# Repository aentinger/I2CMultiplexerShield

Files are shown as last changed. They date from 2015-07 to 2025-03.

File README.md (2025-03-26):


💾 I2C Multiplexer Shield
=========================



# 📸 Image

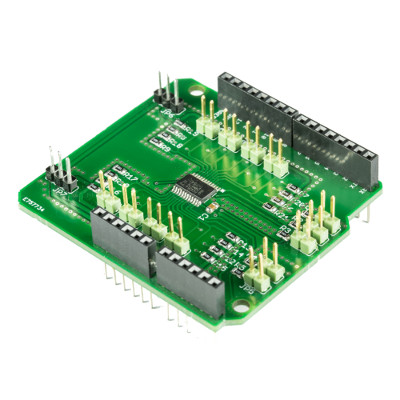
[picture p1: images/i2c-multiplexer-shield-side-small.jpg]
LXRobotics P19 I2C Multiplexer Shield


# 📂 Description

Originally many I2C slave devices as temperature sensors, distance sensors, RAM/ROM, digital I/O expanders had only a single I2C address. As a consequence, only one such I2C slave could be operated on one I2C. If one wanted to operate multiple I2C slaves with identical address, multiple I2C buses with its own I2C master were necessary. To overcome this limitation, modern I2C slaves have a base address, which can be varied by setting of '0' and '1' on special address pins. Thereby, typically between 4 and 8 different addresses are required per I2C slave. But if onw would want to use more than the addresses offered by the I2C slave device, so again several I2C buses with its own I2C master are necessary.

The LXRobotics I2C Multiplexer Shield solves this problem by allowing the user to switch back and forth between 8 different I2C bus systems. The I2C Multiplexer Shield acts also as a level converter, so that 3,3 V I2C sensors can easily interact with the Arduino. For the quick start, a finished Arduino Library with sample programs is available

**Features**

* Control nearly any number of (similar) sensors over a single I2C bus
* Multiplexing of 8 different I2C buses on 1 I2C bus
* I2C-Pullups via Jumper shiftable
* Selection of the I2C bus voltage between 5 V and 3,3 V via jumper possible (optionally, can be also fed any arbitrary I2C bus voltage)
* Up to 8 different I2C addresses of the I2C Multiplexer Shields configurable via jumper
* Arduino Library available for control with example programms

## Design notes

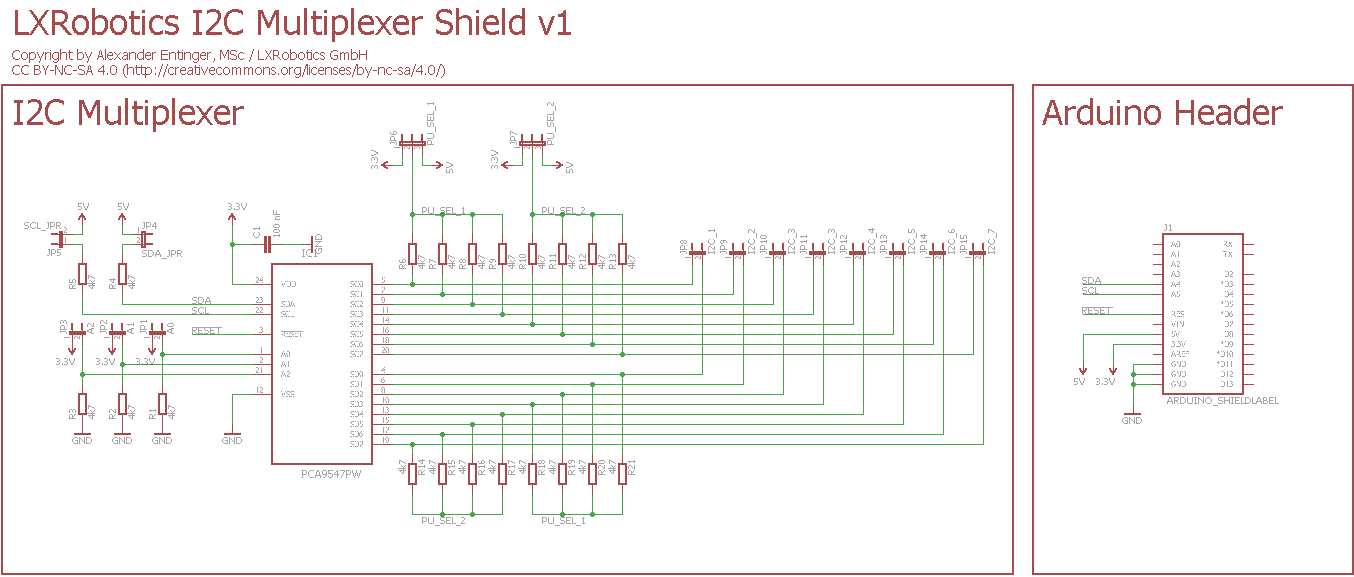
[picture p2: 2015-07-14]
hardware/lxr_i2c_multiplexer_shield_v1.png

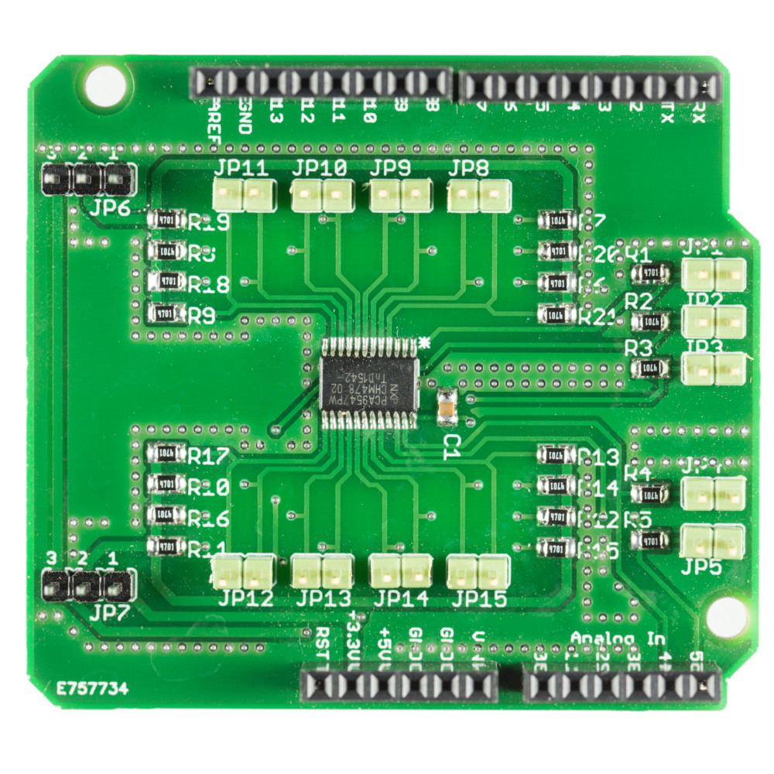
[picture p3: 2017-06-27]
images/i2c-multiplexer-shield-top-large.jpg

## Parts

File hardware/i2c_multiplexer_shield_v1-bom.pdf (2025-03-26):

Menge | Schaltplan | Bezeichnung | Farnell Bestell Nummer | Preis (1 Stück) | Gesamtpreis | Wird bestückt | Footprint | Säckchen
1 | IC1 | PCS9547PW | 2212121 | € 2,41 | € 2,41 | X
13 | JP1-JP5,JP8-JP15 | Stiftleiste, 1 x 2, 2.54 mm, Vertikal, Durchsteck | 3418285 | € 0,24 | € 3,12 | | | S1
21 | R1-R21 | 4k7, 0805, Widerstand SMD | 1469923 | € 0,02 | € 0,42 | X
2 | JP6,JP7 | Stiftleiste, 3-Polig, 2.54 mm | 1022249 | € 0,19 | € 0,38 | | | S1
1 | C1 | Kondensator, 100 nF, 16 V, 0805 | 1759144 | € 0,01 | € 0,01 | X
7 | | Jumper, 2.54 mm, 2 Polig | 4218176 | € 0,14 | € 0,98 | | | S1
1 | J1 | Satz Arduino Buchsenleisten | ELV | € | 0,75 | € | 0,75 | S2 | http://www.elv.at/buchsenleisten-set-fuer-arduino-boards.html
| | | | Summe | | € | 8,07

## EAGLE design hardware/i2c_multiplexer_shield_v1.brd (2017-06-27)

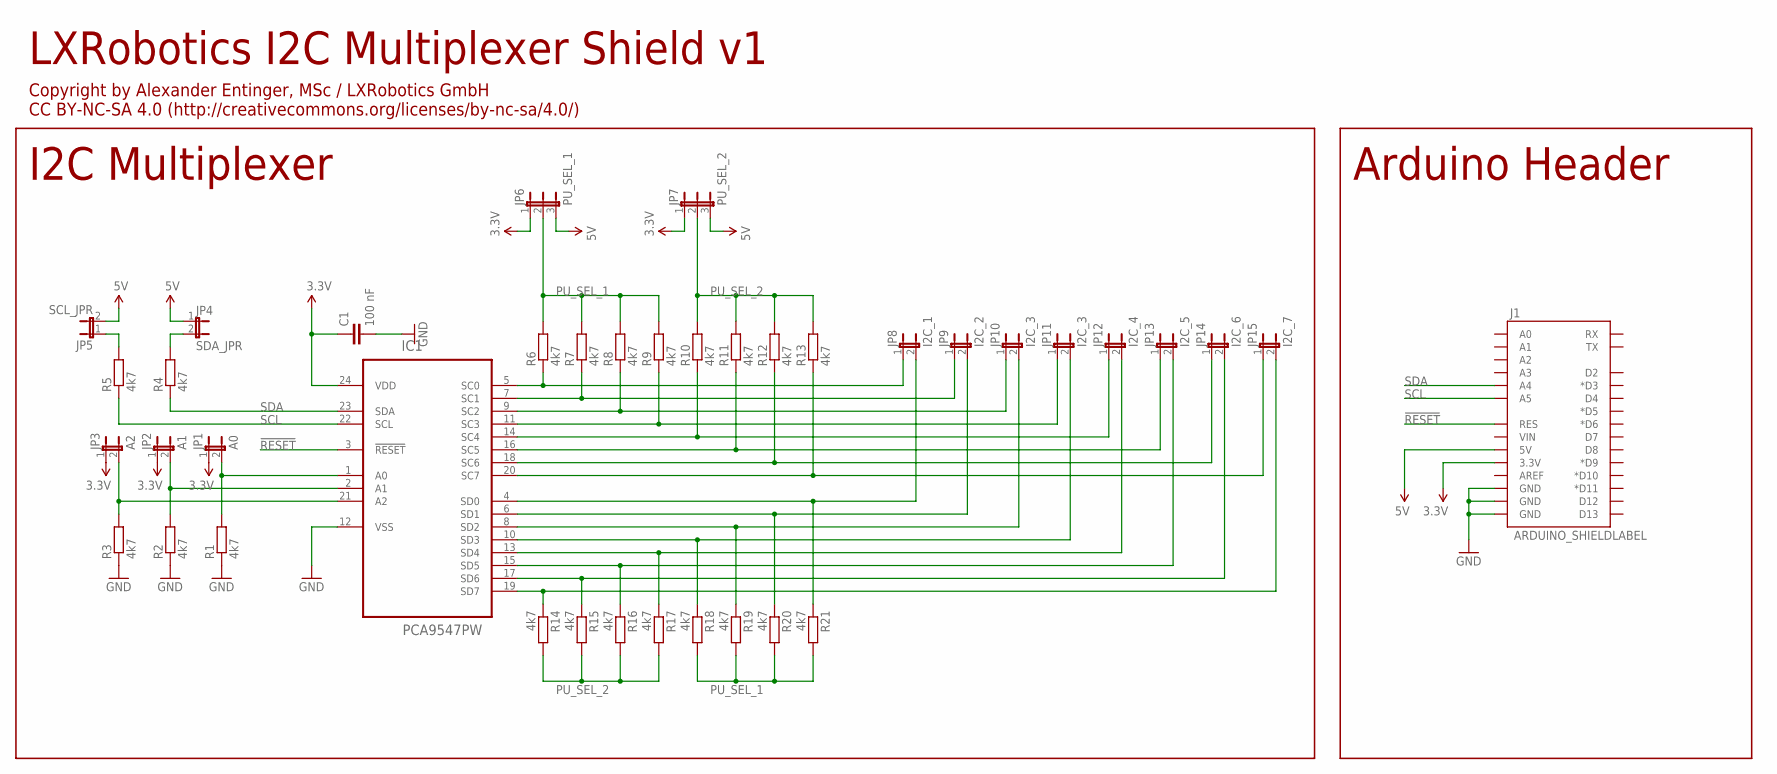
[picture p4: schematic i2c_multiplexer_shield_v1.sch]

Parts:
C1: 100 nF; C0805
IC1: PCA9547PW; SOP65P640X110-24N
J1: ARDUINO_SHIELDLABEL; DUEMILANOVE_SHIELD
JP1: A0; JP1
JP2: A1; JP1
JP3: A2; JP1
JP4: SDA_JPR; JP1
JP5: SCL_JPR; JP1
JP6: PU_SEL_1; JP2
JP7: PU_SEL_2; JP2
JP8: I2C_1; JP1
JP9: I2C_2; JP1
JP10, JP11: I2C_3; JP1
JP12: I2C_4; JP1
JP13: I2C_5; JP1
JP14: I2C_6; JP1
JP15: I2C_7; JP1
R1, R2, R3, R4, R5, R6, R7, R8, R9, R10, R11, R12, R13, R14, R15, R16, R17, R18, R19, R20, R21: 4k7; R0805

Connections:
3.3V: C1.1, IC1.24 (VDD), J1.3.3V, JP1.1, JP2.1, JP3.1, JP6.1, JP7.1
5V: J1.5V, JP4.1, JP5.2, JP6.3, JP7.3
!RESET: IC1.3 (!RESET), J1.RES
GND: C1.2, IC1.12 (VSS), J1.GND@0 (GND), J1.GND@1 (GND), J1.GND@2 (GND), R1.1, R2.1, R3.1
unnamed: IC1.1 (A0), JP1.2, R1.2
unnamed: IC1.2 (A1), JP2.2, R2.2
unnamed: IC1.21 (A2), JP3.2, R3.2
unnamed: JP5.1, R5.2
unnamed: JP4.2, R4.2
unnamed: IC1.5 (SC0), JP8.1, R6.1
unnamed: IC1.7 (SC1), JP9.1, R7.1
unnamed: IC1.9 (SC2), JP10.1, R8.1
unnamed: IC1.11 (SC3), JP11.1, R9.1
unnamed: IC1.14 (SC4), JP12.1, R10.1
unnamed: IC1.16 (SC5), JP13.1, R11.1
unnamed: IC1.18 (SC6), JP14.1, R12.1
unnamed: IC1.20 (SC7), JP15.1, R13.1
unnamed: IC1.4 (SD0), JP8.2, R21.1
unnamed: IC1.6 (SD1), JP9.2, R20.1
unnamed: IC1.8 (SD2), JP10.2, R19.1
unnamed: IC1.10 (SD3), JP11.2, R18.1
unnamed: IC1.13 (SD4), JP12.2, R17.1
unnamed: IC1.15 (SD5), JP13.2, R16.1
unnamed: IC1.17 (SD6), JP14.2, R15.1
unnamed: IC1.19 (SD7), JP15.2, R14.1
PU_SEL_1: JP6.2, R6.2, R7.2, R8.2, R9.2, R18.2, R19.2, R20.2, R21.2
PU_SEL_2: JP7.2, R10.2, R11.2, R12.2, R13.2, R14.2, R15.2, R16.2, R17.2
SCL: IC1.22 (SCL), J1.A5, R5.1
SDA: IC1.23 (SDA), J1.A4, R4.1

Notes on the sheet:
I2C Multiplexer
Arduino Header
LXRobotics I2C Multiplexer Shield v1
Copyright by Alexander Entinger, MSc / LXRobotics GmbH CC BY-NC-SA 4.0 (http://creativecommons.org/licenses/by-nc-sa/4.0/)

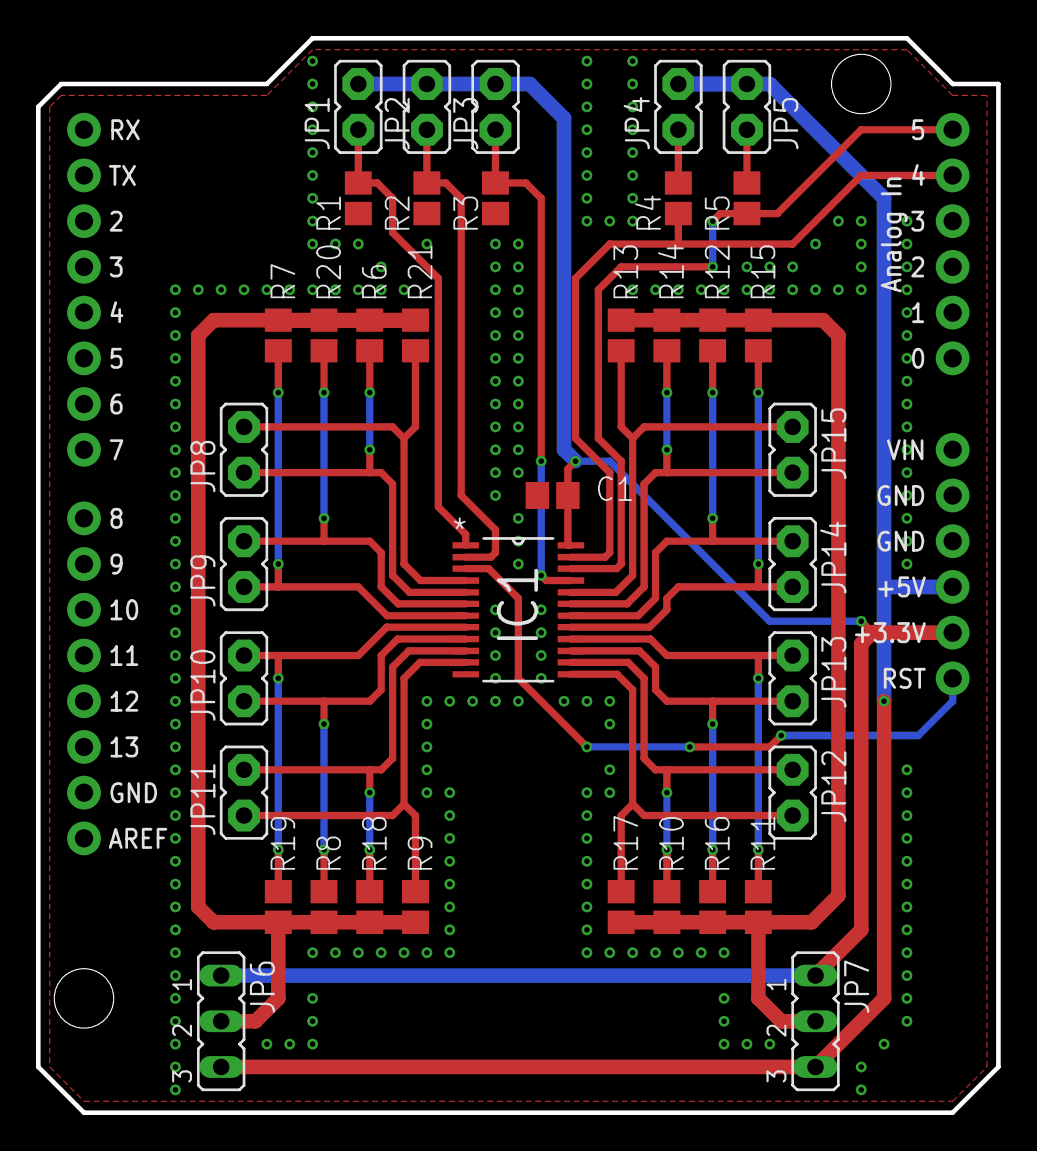
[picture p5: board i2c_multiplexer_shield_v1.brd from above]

Board: 2 copper layers, 53.3 x 59.7 mm, 39 parts (0 on the bottom side), 29 nets.

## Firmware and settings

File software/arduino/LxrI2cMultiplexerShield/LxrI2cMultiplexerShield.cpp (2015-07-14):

/**
 * @author Alexander Entinger, MSc / LXRobotics
 * @brief this module implements the library for controlling the LXRobotics I2C Multiplexer Shield for switching between up to 8 separate i2c busses
 * @file LxrI2cMultiplexerShield.cpp
 * @license Attribution-NonCommercial-ShareAlike 4.0 Unported (CC BY-NC-SA 4.0) ( http://creativecommons.org/licenses/by-nc-sa/4.0/ )
 */
 
#include "LxrI2cMultiplexerShield.h"
 
#include <Wire.h>

/**
 * @brief Constructor
 */
LxrI2cMultiplexerShield::LxrI2cMultiplexerShield(byte const i2c_multiplexer_address) : _i2c_multiplexer_address(i2c_multiplexer_address)
{
    
}

/**
 * @brief initializes the library
 */
void LxrI2cMultiplexerShield::begin()
{
  Wire.begin();
}

/**
 * @brief select a specific channel
 */
void LxrI2cMultiplexerShield::set_channel(E_I2C_CHANNEL_SELECT const sel)
{
  Wire.beginTransmission(_i2c_multiplexer_address);
  Wire.write((byte)(sel));
  Wire.endTransmission();
}

/**
 * @brief reads out the current selected channel
 */
E_I2C_CHANNEL_SELECT LxrI2cMultiplexerShield::get_channel()
{
  Wire.requestFrom(_i2c_multiplexer_address, (byte)(1));
  return (E_I2C_CHANNEL_SELECT)(Wire.read());
}

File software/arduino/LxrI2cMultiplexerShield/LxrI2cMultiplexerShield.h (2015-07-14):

/**
 * @author Alexander Entinger, MSc / LXRobotics
 * @brief this module implements the library for controlling the LXRobotics I2C Multiplexer Shield for switching between up to 8 separate i2c busses
 * @file LxrI2cMultiplexerShield.h
 * @license Attribution-NonCommercial-ShareAlike 4.0 Unported (CC BY-NC-SA 4.0) ( http://creativecommons.org/licenses/by-nc-sa/4.0/ )
 */

#ifndef LXRI2CMULTIPLEXERSHIELD_H_
#define LXRI2CMULTIPLEXERSHIELD_H_
 
 /* INCLUDES */
 
#include "Arduino.h"

/* GLOBAL CONSTANTS */

static byte const I2C_MULTIPLEXER_SHIELD_NO_JUMPERS_SET = 0x70;
static byte const I2C_MULTIPLEXER_SHIELD_ALL_JUMPERS_SET = 0x77;

/* TYPEDEFS */

typedef enum
{
  I2C_CHANNEL_0 = 0b00001000,
  I2C_CHANNEL_1 = 0b00001001,
  I2C_CHANNEL_2 = 0b00001010,
  I2C_CHANNEL_3 = 0b00001011,
  I2C_CHANNEL_4 = 0b00001100,
  I2C_CHANNEL_5 = 0b00001101,
  I2C_CHANNEL_6 = 0b00001110,
  I2C_CHANNEL_7 = 0b00001111,
  I2C_NO_CHANNEL = 0b00000000
} E_I2C_CHANNEL_SELECT;

/* PROTOTYPES */

class LxrI2cMultiplexerShield
{
	
public:

  /**
   * @brief Constructor
   */
  LxrI2cMultiplexerShield(byte const i2c_multiplexer_address);

  /**
   * @brief initializes the library
   */
  void begin();

  /**
   * @brief select a specific channel
   */
  void set_channel(E_I2C_CHANNEL_SELECT const sel);

  /**
   * @brief reads out the current selected channel
   */
  E_I2C_CHANNEL_SELECT get_channel();  

private:

  byte _i2c_multiplexer_address;
  
};

#endif

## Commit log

2015-07-14 initial checkin of multiplexer i2c shield
2015-07-14 checkin in software library for i2c multiplexer shield
2017-06-27 Adding hardware + images
    [i2c_multiplexer_shield_v1.brd, i2c_multiplexer_shield_v1.sch]
2025-03-26 Upload BOM.

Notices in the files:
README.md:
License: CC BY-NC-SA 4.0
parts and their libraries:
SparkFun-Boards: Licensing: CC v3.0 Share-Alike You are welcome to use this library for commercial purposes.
